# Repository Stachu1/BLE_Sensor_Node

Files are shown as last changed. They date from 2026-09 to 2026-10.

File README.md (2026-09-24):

# BLE Sensor Node

**BEng in Electronics Engineering thesis project, focused on low-power design and RF performance.**

A compact, coin-cell-powered Bluetooth Low Energy sensor node that measures temperature and
humidity and advertises the data periodically, without needing a persistent connection.

## Goal

Keep average current low enough for multi-year operation on a single CR2032 cell, while staying
within a small form factor. Main areas of work: low-power firmware and advertising strategy,
antenna/RF performance (chip vs. trace antenna), and power budgeting around the coin cell's
current limits.

Two BLE MCUs are being evaluated in parallel: **Nordic nRF54L** and **TI CC2340R5**.

## Repository Structure

```
hardware/
  N54/          BSN-N54 - Nordic nRF54L variant (KiCad project BSN-N54.kicad_pro)
  C23/          BSN-C23 - TI CC2340R5 variant
firmware/
  N54/          Firmware for BSN-N54 boards
  C23/          Firmware for BSN-C23 boards
docs/           Notes, datasheets, write-ups
results/        Power profiling logs, range-test data
```

The two MCU candidates are different chips (different pinout, power tree, likely BOM) rather
than build options of one board, so each gets its own KiCad project under `hardware/<variant>/`
and its own `firmware/<variant>/`, where `<variant>` is the variant code below. Both live side by side on `main` and iterate through normal
commits. Once a chip is selected, the other candidate's folder can be
archived or removed.

## Naming Scheme

Each board is identified as **`BSN-<variant>-<revision>`**, e.g. `BSN-N54-A`.

```
BSN-N54-A
 │   │  └─ PCB revision  (A, B, C …)
 │   └──── MCU variant   (N54 = Nordic nRF54L, C23 = TI CC2340R5)
 └──────── Board name    (BSN = BLE Sensor Node)
```

| Part | Values | Meaning |
|---|---|---|
| Board | `BSN` | BLE Sensor Node. Never changes. |
| Variant | `N54`, `C23` | First letter of the MCU part prefix (**n**RF54 → N, **C**C2340 → C) + MCU family number. Stays the same across parts in one family (e.g. nRF54L05/L10/L15). |
| Revision | `A`, `B`, `C` | Bare-PCB revision. Bumped only when copper or fab outputs change, i.e. when new boards are ordered. |
| Assembly option *(optional)* | e.g. `-UFL` | Population option on the same bare PCB (e.g. U.FL fitted instead of the chip antenna). Does not change the revision. |

Rules:

- **Each variant has its own revision counter.** `BSN-N54-C` and `BSN-C23-A` can exist at the same time.
- **Letters are only for boards that were ordered.** Work in progress before an order is still the upcoming letter.
  Once gerbers are sent to the fab that letter is frozen, and any later change means the next letter.
- **Reworked boards are not new revisions.** A hand-modified board is marked `A*` and the rework is noted in the variant README.
- **The ID is on the board itself.** The revision is set in the KiCad title block, and the ID is printed on the silkscreen.

Where the name appears:

| Item | Example |
|---|---|
| Hardware / firmware folder | `hardware/N54/`, `firmware/N54/` |
| KiCad project | `hardware/N54/BSN-N54.kicad_pro` |
| BOM in the repo | `hardware/N54/BSN-N54_BOM.csv` |
| Exported fab package | `BSN-N54-A_gerbers.zip`, `BSN-N54-A_BOM.csv`, `BSN-N54-A_pos.csv` |
| Git tag on the ordered commit | `hw/BSN-N54-A` |
| Firmware | board target `BSN_N54`, hardware revision `A` (also reported in the BLE Device Information Service) |

Boards:

| Board | MCU | Status |
|---|---|---|
| `BSN-N54-A` | nRF54L05 | Rev A layout done |
| `BSN-C23-A` | CC2340R5 | Copied from `BSN-N54-A`, MCU swap in progress |

## Status

Early stage — component evaluation and initial hardware/firmware design.

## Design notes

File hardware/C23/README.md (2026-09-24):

# BSN-C23 (TI CC2340R5 variant)

KiCad project: `BSN-C23.kicad_pro`. See the root README for the board naming scheme.

## Starting point

This project started as a copy of `BSN-N54-A` (board outline, power, sensors, antenna and
test points). Some parts are still nRF54L-specific and need to be replaced:

- [ ] U1: swap the nRF54L05 for the CC2340R52E0RGER (VQFN-24 4x4, RGE)
- [ ] Decoupling and power tree for the CC2340R5 (DC/DC inductor, VDDS/VDDR caps)
- [ ] 48 MHz HF crystal (the CC2340R5 uses 48 MHz; Y1 is currently the nRF 32 MHz part)
- [ ] RF matching network and filter per the TI CC2340R5 reference design
- [ ] Debug header: SWD pins for the CC2340R5

## CC2340R5 design resources

There is no CC2340 part in the official KiCad library and no TI equivalent of Nordic's
KiCad design blocks, so the design blocks table is empty for now.

| Resource | Format | Link |
|---|---|---|
| CC2340R5 symbol + footprint + STEP (RGE VQFN-24 4x4) | KiCad v6+ export via Ultra Librarian (free login) | https://vendor.ultralibrarian.com/TI/embedded/?gpn=CC2340R5&package=RGE&pin=24 |
| LP-EM-CC2340R53 LaunchPad design files (uses the 40-pin RKP package, but the RF, crystal and DC/DC circuits carry over) | Allegro/OrCAD + schematic/layout PDF, BOM, Gerbers, ODB++ | https://www.ti.com/lit/zip/SWRC397 |
| LP-EM-CC2340R53 user guide | PDF | https://www.ti.com/lit/pdf/SWRU637 |
| CC234x/CC27xx hardware configuration & PCB design (SWRA834) | PDF | https://www.ti.com/lit/pdf/SWRA834 |
| Product page (packages, docs) | Web | https://www.ti.com/product/CC2340R5 |

### CC2340R5 part in the `BSN-C23` library

| Part | Symbol | Footprint | 3D model |
|---|---|---|---|
| CC2340R52E0RGER (VQFN-24 4x4) | `CC2340R52E0RGER` | `Texas_RGE0024B_VQFN-24-1EP_4x4mm_P0.5mm_EP2.45x2.45mm_ThermalVias` | `Texas_RGE0024H_VQFN-24-1EP_4x4mm_P0.5mm_EP2.7x2.7mm.step` |

These were made here from the datasheet and KiCad's stock library rather than downloaded:

- **Symbol:** drawn from the datasheet (SWRS272F), Figure 6-2 and Tables 6-1 to 6-13. The exposed pad is pin 25 (GND).
- **Footprint:** KiCad's stock `VQFN-24-1EP_4x4mm_P0.5mm_EP2.45x2.45mm_ThermalVias`, renamed. It matches TI's RGE0024B land pattern (2.45 mm pad, 9 vias on a 0.975 mm grid). The signal pads are 0.775 mm long versus 0.6 mm in TI's example.
- **3D model:** KiCad has no STEP file for the 2.45 mm pad version. This one is the TI RGE0024H body, which is identical apart from a 2.7 mm exposed pad hidden under the package.

Next step: copy the RF matching network, crystals and DC/DC layout from the SWRC397 LaunchPad files.

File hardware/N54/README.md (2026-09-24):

# BSN-N54 (Nordic nRF54L variant)

KiCad project: `BSN-N54.kicad_pro`. See the root README for the board naming scheme.

## ANT-pin matching network

The antenna matching network on the nRF54L05 ANT pin (U1 pin 31) is a
3-section ladder plus two more tuning elements (L5, L6) leading to the
antenna-select junction (AE1 chip antenna / J1 SMA test point):

```
U1.ANT(31) -- L2(2.7n) --o-- L3(3.5n) --o-- L4(3.5n) --o-- L5(7.3n) -- L6(6.7n) -- (AE1 / J1)
                          |              |              |
                         C14(1.5p)      C15(2.0p)      C16(0.3p)
                          |              |              |
                         GND            GND            GND
```

From the nRF54L and antenna datasheets I estimated both the MCU ANT-pin
source impedance and the actual antenna impedance. Worked through on a
Smith chart, stepping from the estimated MCU source impedance through all
8 elements to the antenna:

https://onlinesmithchart.com/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

## Simplified 3-element equivalent

Considering a simplified network that achieves the same impedance
translation straight from the MCU source to the antenna, without forcing
the trace through 50 Ω partway — down to just 3 components:

https://onlinesmithchart.com/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

**Caveats:** the 8-element network likely also does 2nd/3rd-harmonic
low-pass filtering for regulatory compliance (FCC/ETSI spurious emissions),
which a bare 3-element network gives up some of; and both circuits above
use idealized lumped components — real inductors/capacitors have
parasitics, and the true MCU/antenna impedances include board parasitics
not captured here. Treat this as a starting point for simulation and bench
(VNA) verification, not a final BOM change.

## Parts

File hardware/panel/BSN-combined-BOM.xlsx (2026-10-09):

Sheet: Combined BOM
BLE Sensor Node - combined BOM (BSN-C23 + BSN-N54)
Generated from hardware/C23/BSN-C23.csv and hardware/N54/BSN-N54.csv. DNP-only parts (no part number) are not included.
Boards to build
BSN-C23 boards |  | 5 | Default 2 = one panel (2x C23 + 2x N54, see panel/panelize.py). Change to match the order.
BSN-N54 boards |  | 5
How to use
Yellow cells are for you to fill in: board counts above, Order qty and Unit price in the tables. Required qty = qty per board x boards to build. Total price = Order qty x Unit price.
Table 1 - DigiKey parts
# | DigiKey PN | Manufacturer | MPN | Value | Package | Description | C23 refs | C23 qty/board | N54 refs | N54 qty/board | Required qty | Order qty | Unit price | Total price | Notes
1 | 490-11248-1-ND | Murata | GJM1555C1HR30WB01D | 0.3p | 0402 | Cap 0.3pF 50V C0G |  | 0 | C16 | 1 | 5 | 10 | 0.52 | 5.24
2 | 490-8087-1-ND | Murata | GJM1555C1H1R5BB01D | 1.5p | 0402 | Cap 1.5pF 50V C0G | C7,C8 | 2 | C14 | 1 | 15 | 20 | 0.36 | 7.20
3 | 1276-CL21A107MQYNNWECT-ND | Murata | GRM21BR60J107ME15K | 100u | 0805 | Cap 100uF 6.3V X5R | C5 | 1 | C10 | 1 | 10 | 10 | 5.27 | 52.66
4 | 490-4516-1-ND | Murata | GRM155R71H103KA88D | 10n | 0402 | Cap 10nF 50V X7R |  | 0 | C8,C9 | 2 | 10 | 10 | 0.14 | 1.44
5 | 490-11191-1-ND | Murata | GJM1555C1H150FB01D | 15p | 0402 | Cap 15pF 50V C0G | C6 | 1 |  | 0 | 5 | 10 | 0.50 | 4.98
6 | 490-11205-1-ND | Murata | GJM1555C1H2R0WB01D | 2.0p | 0402 | Cap 2.0pF 50V C0G |  | 0 | C15 | 1 | 5 | 10 | 0.52 | 5.24
7 | 445-9028-1-ND | TDK | C1005X5R1V225K050BC | 2.2u | 0402 | Cap 2.2uF 35V X5R |  | 0 | C6,C7 | 2 | 10 | 10 | 0.76 | 7.60
8 | 490-15398-1-ND | Murata | LQW15AN2N7G8ZD | 2.7n | 0402 | Inductor 2.7nH RF |  | 0 | L2 | 1 | 5 | 10 | 0.90 | 9.04
9 | 490-LQW15AN2N8G80DCT-ND | Murata | LQW15AN2N8G80D | 2.8n | 0402 | Inductor 2.8nH RF | L1 | 1 |  | 0 | 5 | 10 | 0.88 | 8.78
10 | 490-15430-1-ND | Murata | LQW15AN3N5G8ZD | 3.5n | 0402 | Inductor 3.5nH RF |  | 0 | L3,L4 | 2 | 10 | 25 | 0.84 | 20.96
11 | 728-1074-1-ND | Seiko Instruments | SC32S-7PF20PPM | 32.768kHz | 3.2x1.5mm 2-pad | Crystal 32.768kHz |  | 1 | X2 | 1 | 10 | 10 | 2.47 | 24.69
12 | 478-CX3225FB32000C0FZZH1CT-ND | Kyocera AVX | CX3225FB32000C0FZZH1 | 32MHz | 3.2x2.5mm 4-pad | Crystal 32MHz |  | 0 | X1 | 1 | 5 | 10 | 1.95 | 19.45
13 | 490-12065-1-ND | Murata | LQM18PN4R7MFRL | 4.7u | 0603 | Inductor 4.7uH |  | 0 | L1 | 1 | 5 | 10 | 1.36 | 13.62
14 | 50-ECS-480-8-33B-CWN-TR3CT-ND | ECS Inc. | ECS-480-8-33B-CWN-TR3 | 48MHz | 3.2x2.5mm 4-pad | Crystal 48MHz | X1 | 1 |  | 0 | 5 | 10 | 2.77 | 27.71
15 | LQW15AN6N7G8ZD | Murata | LQW15AN6N7B00D | 6.7n | 0402 | Inductor 6.7nH RF | L2 | 1 | L6 | 1 | 10 | 25 | 0.84 | 20.96
16 | 490-6844-1-ND | Murata | LQW15AN7N3G00D | 7.3n | 0402 | Inductor 7.3nH RF | L3 | 1 | L5 | 1 | 10 | 25 | 0.63 | 15.72
17 | 535-AANI-CH-0138-Q-TCT-ND | Abracon | AANI-CH-0138-Q-T | AANI-CH-0138-Q-T | 7.0x2.0mm SMD | 2.4 GHz chip antenna | AE1 | 1 | AE1 | 1 | 10 | 10 | 5.14 | 51.42
18 | 296-CC2340R52E0RGERCT-ND | Texas Instruments | CC2340R52E0RGER | CC2340R52E0RGER | VQFN-24 4x4mm | BLE SoC | U1 | 1 |  | 0 | 5 | 10 | 17.94 | 179.40
19 | 123-A-BAT-CH-C8-EA-ZSR3CT-ND | Assmann WSW | A-BAT-CH-C8-EA-ZSR3 | CR2032_Holder | SMD | CR2032 coin cell holder | BT1 | 1 | BT1 | 1 | 10 | 10 | 3.54 | 35.37 | PCB footprint is Renata SMTU2032-LF, not this holder - check before ordering
20 | H11891CT-ND | Hirose | U.FL-R-SMT-1(10) | Conn_Coaxial_Small | SMD | U.FL receptacle, vertical | J1 | 1 | J1 | 1 | 10 | 10 | 9.28 | 92.81 | DNP on both boards (only for RF testing)
21 | 296-47774-1-ND | Texas Instruments | HDC2010YPAR | HDC2010 | DSBGA-6 | Humidity/temp sensor | U3 | 1 | U3 | 1 | 10 | 25 | 9.54 | 238.55
22 | 1649-SHTC3-TR-2.5KSCT-ND | Sensirion | SHTC3-TR-2.5KS | SHTC3 | DFN-4 2x2mm | Humidity/temp sensor | U2 | 1 | U2 | 1 | 10 | 5 | 12.48 | 62.42 | DNP on both boards (alternative to HDC2010)
23 | 4823-NRF54L05-QFAA-RCT-ND | Nordic Semiconductor | NRF54L05-QFAA-R | nRF54L05-QFXX | QFN-48 6x6mm | BLE SoC |  | 0 | U1 | 1 | 5 | 10 | 21.51 | 215.10
24 | 1568-18569-ND | SparkFun Electronics | 18569 |  |  |  |  |  |  |  | 1 | 2 | 19.26 | 38.52
25 | 315-NC191LT10-ND | Chip Quik Inc. | NC191LT10 |  |  |  |  |  |  |  | 1 | 1 | 52.07 | 52.07
 |  |  |  |  |  |  |  |  |  |  |  |  | Subtotal | 1210.95
Table 2 - AX parts
# | AX no. |  |  | Value | Package | Description | C23 refs | C23 qty/board | N54 refs | N54 qty/board | Required qty | Order qty | Unit price | Total price | Notes
1 | 73236 |  |  | 100R@100MHz | 0603 | Ferrite bead |  | 0 | FB1 | 1 | 5
2 | 201003 |  |  | 100k | 0402 | Resistor | R3 | 1 |  | 0 | 5
3 | 27726 |  |  | 100n | 0402 | Capacitor | C2,C3,C4,C11,C12,C17,C18 | 7 | C2,C3,C4,C5,C12,C13 | 6 | 65
4 | 27204 |  |  | 10u | 0603 | Capacitor | C1,C10 | 2 | C1 | 1 | 15
5 | 73170 |  |  | 10u | 0603 | Inductor | L5 | 1 |  | 0 | 5
6 | 201001 |  |  | 1k | 0402 | Resistor |  | 0 | R1 | 1 | 5
7 | 27730 |  |  | 1u | 0402 | Capacitor | C13 | 1 |  | 0 | 5
8 | 204701 |  |  | 4.7k | 0402 | Resistor | R1,R2 | 2 | R2,R3 | 2 | 20
 |  |  |  |  |  |  |  |  |  |  |  |  | Subtotal | 0.00
 |  |  |  |  |  |  |  |  |  |  |  |  | Grand total | 1210.95

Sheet: Sheet1
DigiKey PN | Manufacturer | MPN | Order qty
490-11248-1-ND | Murata | GJM1555C1HR30WB01D | 10
490-8087-1-ND | Murata | GJM1555C1H1R5BB01D | 20
1276-CL21A107MQYNNWECT-ND | Samsung | CL21A107MQYNNWE | 10
490-4516-1-ND | Murata | GRM155R71H103KA88D | 10
490-11191-1-ND | Murata | GJM1555C1H150FB01D | 10
490-11205-1-ND | Murata | GJM1555C1H2R0WB01D | 10
445-9028-1-ND | TDK | C1005X5R1V225K050BC | 10
490-15398-1-ND | Murata | LQW15AN2N7G8ZD | 10
490-LQW15AN2N8G80DCT-ND | Murata | LQW15AN2N8G80D | 10
490-15430-1-ND | Murata | LQW15AN3N5G8ZD | 25
728-1074-1-ND | Seiko Instruments | SC32S-7PF20PPM | 10
478-CX3225FB32000C0FZZH1CT-ND | Kyocera AVX | CX3225FB32000C0FZZH1 | 10
490-12065-1-ND | Murata | LQM18PN4R7MFRL | 10
50-ECS-480-8-33B-CWN-TR3CT-ND | ECS Inc. | ECS-480-8-33B-CWN-TR3 | 10
LQW15AN6N7G8ZD | Murata | LQW15AN6N7B00D | 25
490-6844-1-ND | Murata | LQW15AN7N3G00D | 25
535-AANI-CH-0138-Q-TCT-ND | Abracon | AANI-CH-0138-Q-T | 10
296-CC2340R52E0RGERCT-ND | Texas Instruments | CC2340R52E0RGER | 10
123-A-BAT-CH-C8-EA-ZSR3CT-ND | Assmann WSW | A-BAT-CH-C8-EA-ZSR3 | 10
H11891CT-ND | Hirose | U.FL-R-SMT-1(10) | 10
296-47774-1-ND | Texas Instruments | HDC2010YPAR | 25
1649-SHTC3-TR-2.5KSCT-ND | Sensirion | SHTC3-TR-2.5KS | 5
4823-NRF54L05-QFAA-RCT-ND | Nordic Semiconductor | NRF54L05-QFAA-R | 10
1568-18569-ND | SparkFun Electronics | 18569 | 2
315-NC191LT10-ND | Chip Quik Inc. | NC191LT10 | 1

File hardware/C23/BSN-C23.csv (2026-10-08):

Reference | Qty | Value | DigiKey | AX
AE1 | 1 | AANI-CH-0138-Q-T | 535-AANI-CH-0138-Q-TCT-ND
BT1 | 1 | CR2032_Holder | 123-A-BAT-CH-C8-EA-ZSR3CT-ND
C1,C10 | 2 | 10u |  | 27204
C2,C3,C4,C11,C12,C17,C18 | 7 | 100n |  | 27726
C5 | 1 | 100u | 490-GRM21BR60J107ME15KCT-ND
C6 | 1 | 15p | 490-11191-1-ND
C7,C8 | 2 | 1.5p | 490-8087-1-ND
C13 | 1 | 1u |  | 27730
J1 | 1 | Conn_Coaxial_Small | H11891CT-ND
L1 | 1 | 2.8n | 490-LQW15AN2N8G80DCT-ND
L2 | 1 | 6.7n | 490-LQW15AN6N7B00DCT-ND
L3 | 1 | 7.3n | 490-6844-1-ND
L5 | 1 | 10u |  | 73170
R1,R2 | 2 | 4.7k |  | 204701
R3 | 1 | 100k |  | 201003
U1 | 1 | CC2340R52E0RGER | 296-CC2340R52E0RGERCT-ND
U2 | 1 | SHTC3 | 1649-SHTC3-TR-2.5KSCT-ND
U3 | 1 | HDC2010 | 296-47774-1-ND
X1 | 1 | 48MHz | 50-ECS-480-8-33B-CWN-TR3CT-ND

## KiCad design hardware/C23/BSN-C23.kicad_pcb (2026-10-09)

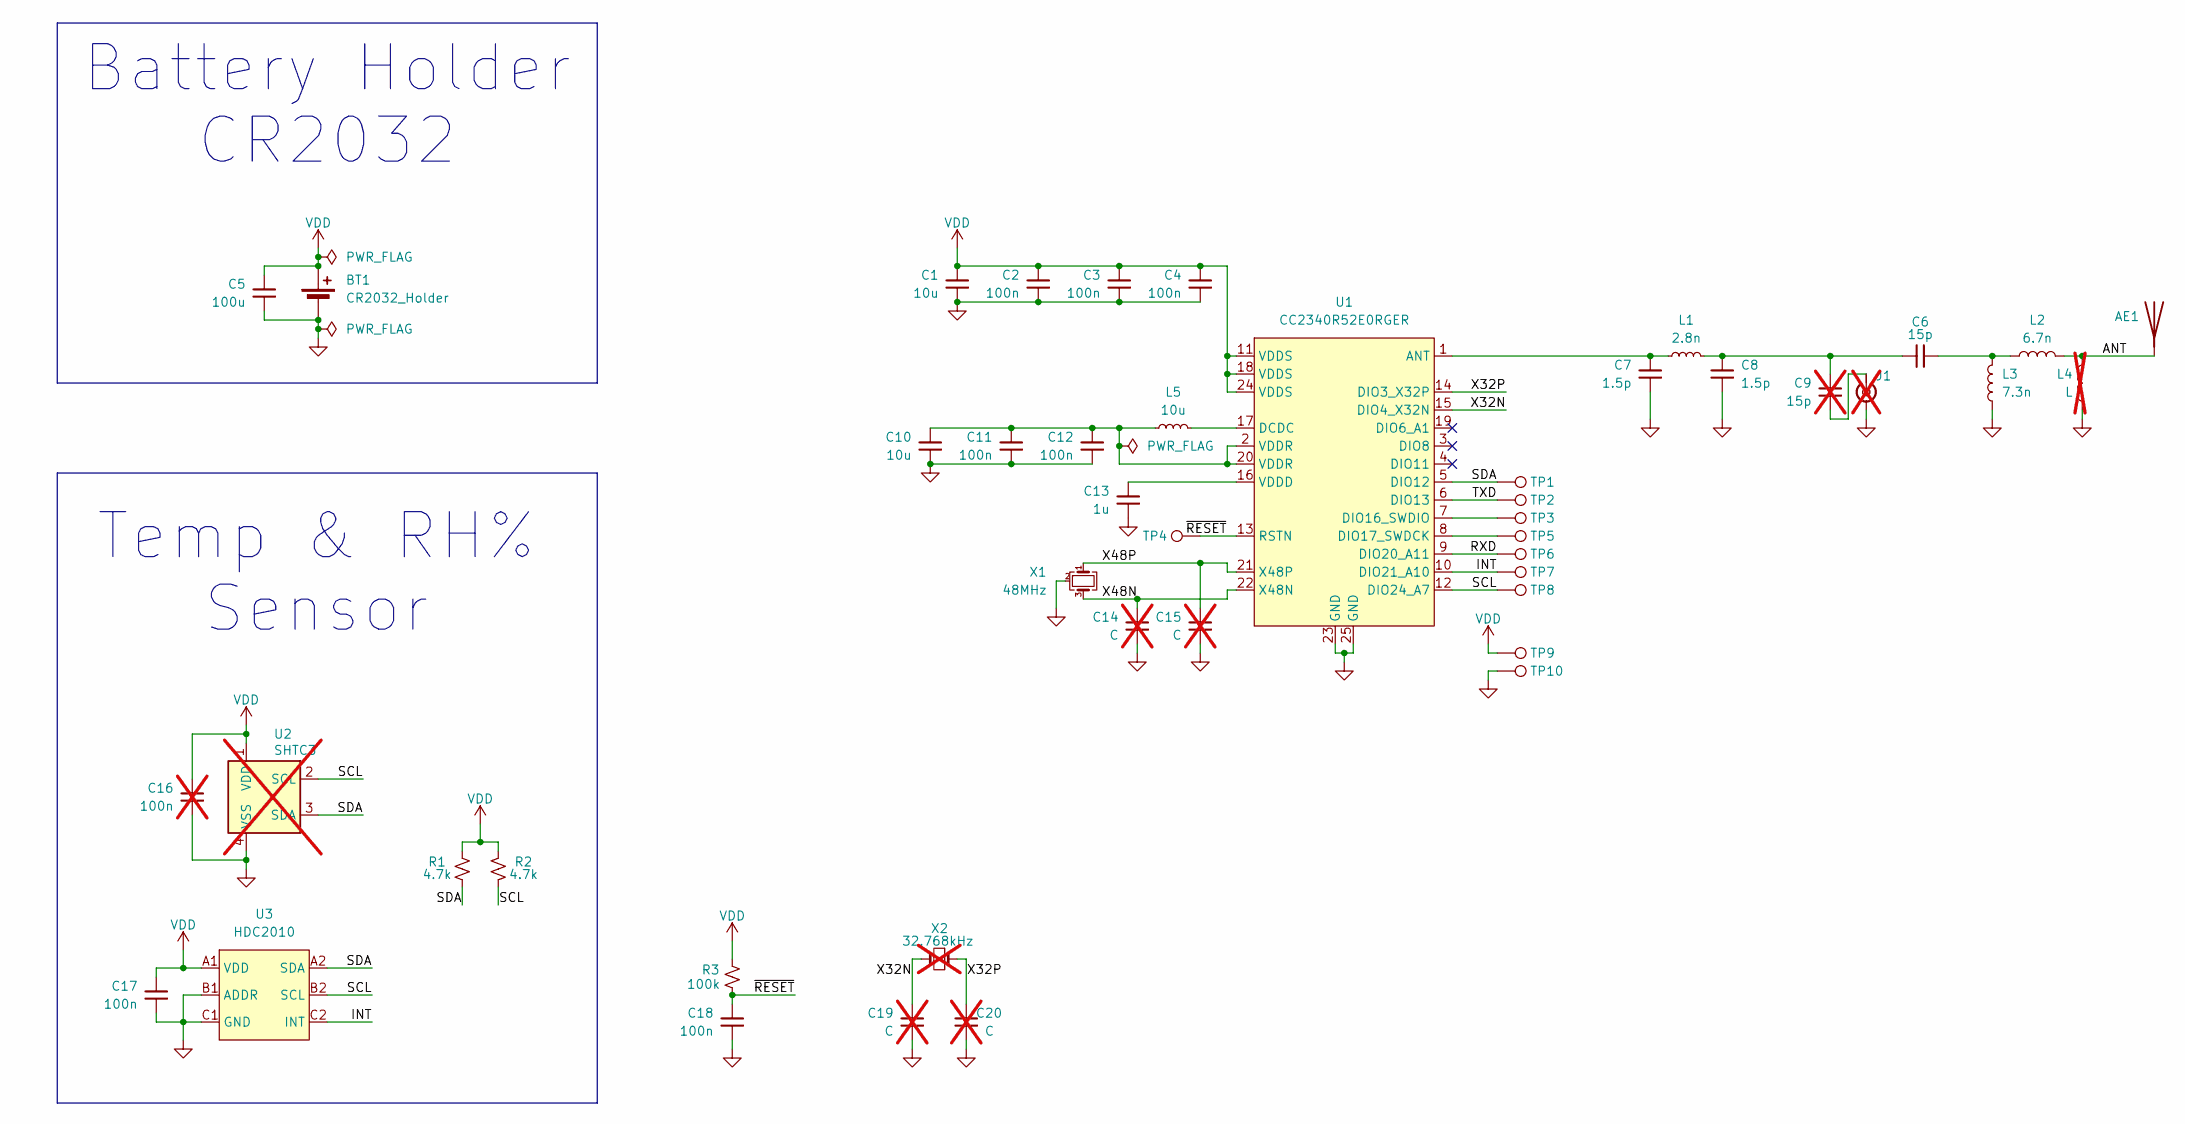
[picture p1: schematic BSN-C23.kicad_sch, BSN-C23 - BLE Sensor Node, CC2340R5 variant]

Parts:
AE1: AANI-CH-0138-Q-T; DigiKey 535-AANI-CH-0138-Q-TCT-ND
BT1: CR2032_Holder; BatteryHolder_Renata_SMTU2032-LF_1x2032; DigiKey 123-A-BAT-CH-C8-EA-ZSR3CT-ND
C1, C10: 10u; C_0603_1608Metric
C2, C3, C4, C11, C12, C17, C18: 100n; C_0402_1005Metric
C5: 100u; C_0805_2012Metric; DigiKey 490-GRM21BR60J107ME15KCT-ND
C6: 15p; C_0402_1005Metric; DigiKey 490-11191-1-ND
C7, C8: 1.5p; C_0402_1005Metric; DigiKey 490-8087-1-ND
C9: 15p; C_0402_1005Metric; DigiKey 490-11191-1-ND; not fitted
C13: 1u; C_0402_1005Metric
C14, C15, C19, C20: C; C_0402_1005Metric; not fitted
C16: 100n; C_0402_1005Metric; not fitted
J1: Conn_Coaxial_Small; U.FL_Hirose_U.FL-R-SMT-1_Vertical; DigiKey H11891CT-ND; not fitted
L1: 2.8n; L_0402_1005Metric; DigiKey 490-LQW15AN2N8G80DCT-ND
L2: 6.7n; L_0402_1005Metric; DigiKey 490-LQW15AN6N7B00DCT-ND
L3: 7.3n; L_0402_1005Metric; DigiKey 490-6844-1-ND
L4: L; L_0402_1005Metric; not fitted
L5: 10u; L_0603_1608Metric
R1, R2: 4.7k; R_0402_1005Metric
R3: 100k; R_0402_1005Metric
TP1, TP2, TP4, TP6, TP7, TP8: TestPoint; TestPoint_Pad_D1.0mm
TP3, TP5, TP9, TP10: TestPoint; TestPoint_Pad_D1.5mm
U1: CC2340R52E0RGER; Texas_RGE0024B_VQFN-24-1EP_4x4mm_P0.5mm_EP2.45x2.45mm_Therm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; DigiKey 296-CC2340R52E0RGERCT-ND
U2: SHTC3; Sensirion_DFN-4-1EP_2x2mm_P1mm_EP0.7x1.6mm; DigiKey 1649-SHTC3-TR-2.5KSCT-ND; not fitted
U3: HDC2010; DigiKey 296-47774-1-ND
X1: 48MHz; Crystal_SMD_3225-4Pin_3.2x2.5mm; DigiKey 50-ECS-480-8-33B-CWN-TR3CT-ND
X2: 32.768kHz; Crystal_SMD_3215-2Pin_3.2x1.5mm; DigiKey 728-1074-1-ND; not fitted

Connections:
/ANT: AE1.1 (Feed_1), L2.2, L4.1
/INT: TP7.1 (1_1), U1.10 (DIO21_A10), U3.C2 (INT)
/RXD: TP6.1 (1_1), U1.9 (DIO20_A11)
/SCL: R2.1, TP8.1 (1_1), U1.12 (DIO24_A7), U2.2 (SCL), U3.B2 (SCL)
/SDA: R1.1, TP1.1 (1_1), U1.5 (DIO12), U2.3 (SDA), U3.A2 (SDA)
/TXD: TP2.1 (1_1), U1.6 (DIO13)
/X32N: C19.1, U1.15 (DIO4_X32N), X2.2
/X32P: C20.1, U1.14 (DIO3_X32P), X2.1
/X48N: C14.1, U1.22 (X48N), X1.3
/X48P: C15.1, U1.21 (X48P), X1.1
/~RESET: C18.1, R3.1, TP4.1 (1_1), U1.13 (RSTN)
GND: BT1.2 (-), C1.2, C2.2, C3.2, C4.2, C5.2, C7.2, C8.2, C10.2, C11.2, C12.2, C13.2, C14.2, C15.2, C16.2, C17.2, C18.2, C19.2, C20.2, J1.2 (Ext), L3.1, L4.2, TP10.1 (1_1), U1.23 (GND), U1.25 (GND), U2.4 (VSS), U3.B1 (ADDR), U3.C1 (GND), X1.2 (G), X1.4 (G)
unnamed: C6.1, L2.1, L3.2
unnamed: C6.2, C8.1, C9.1, L1.2
unnamed: C10.1, C11.1, C12.1, L5.1, U1.2 (VDDR), U1.20 (VDDR)
unnamed: C9.2, J1.1 (In)
unnamed: C7.1, L1.1, U1.1 (ANT)
unnamed: L5.2, U1.17 (DCDC)
unnamed: TP3.1 (1_1), U1.7 (DIO16_SWDIO)
unnamed: TP5.1 (1_1), U1.8 (DIO17_SWDCK)
unnamed: C13.1, U1.16 (VDDD)
VDD: BT1.1 (+), C1.1, C2.1, C3.1, C4.1, C5.1, C16.1, C17.1, R1.2, R2.2, R3.2, TP9.1 (1_1), U1.11 (VDDS), U1.18 (VDDS), U1.24 (VDDS), U2.1 (VDD), U3.A1 (VDD)

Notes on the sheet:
Battery Holder CR2032
Temp & RH% Sensor

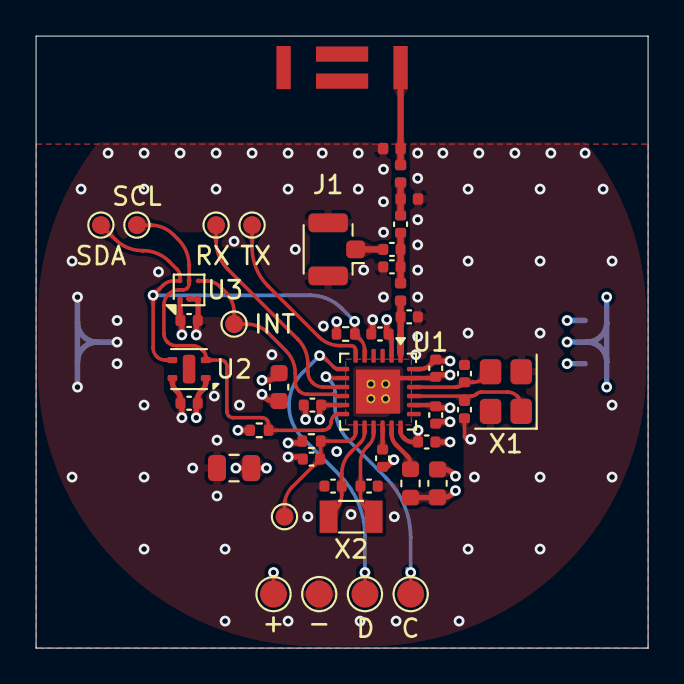
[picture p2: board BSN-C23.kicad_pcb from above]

Board: 4 copper layers, 34.0 x 34.0 mm, 46 parts (1 on the bottom side), 22 nets.

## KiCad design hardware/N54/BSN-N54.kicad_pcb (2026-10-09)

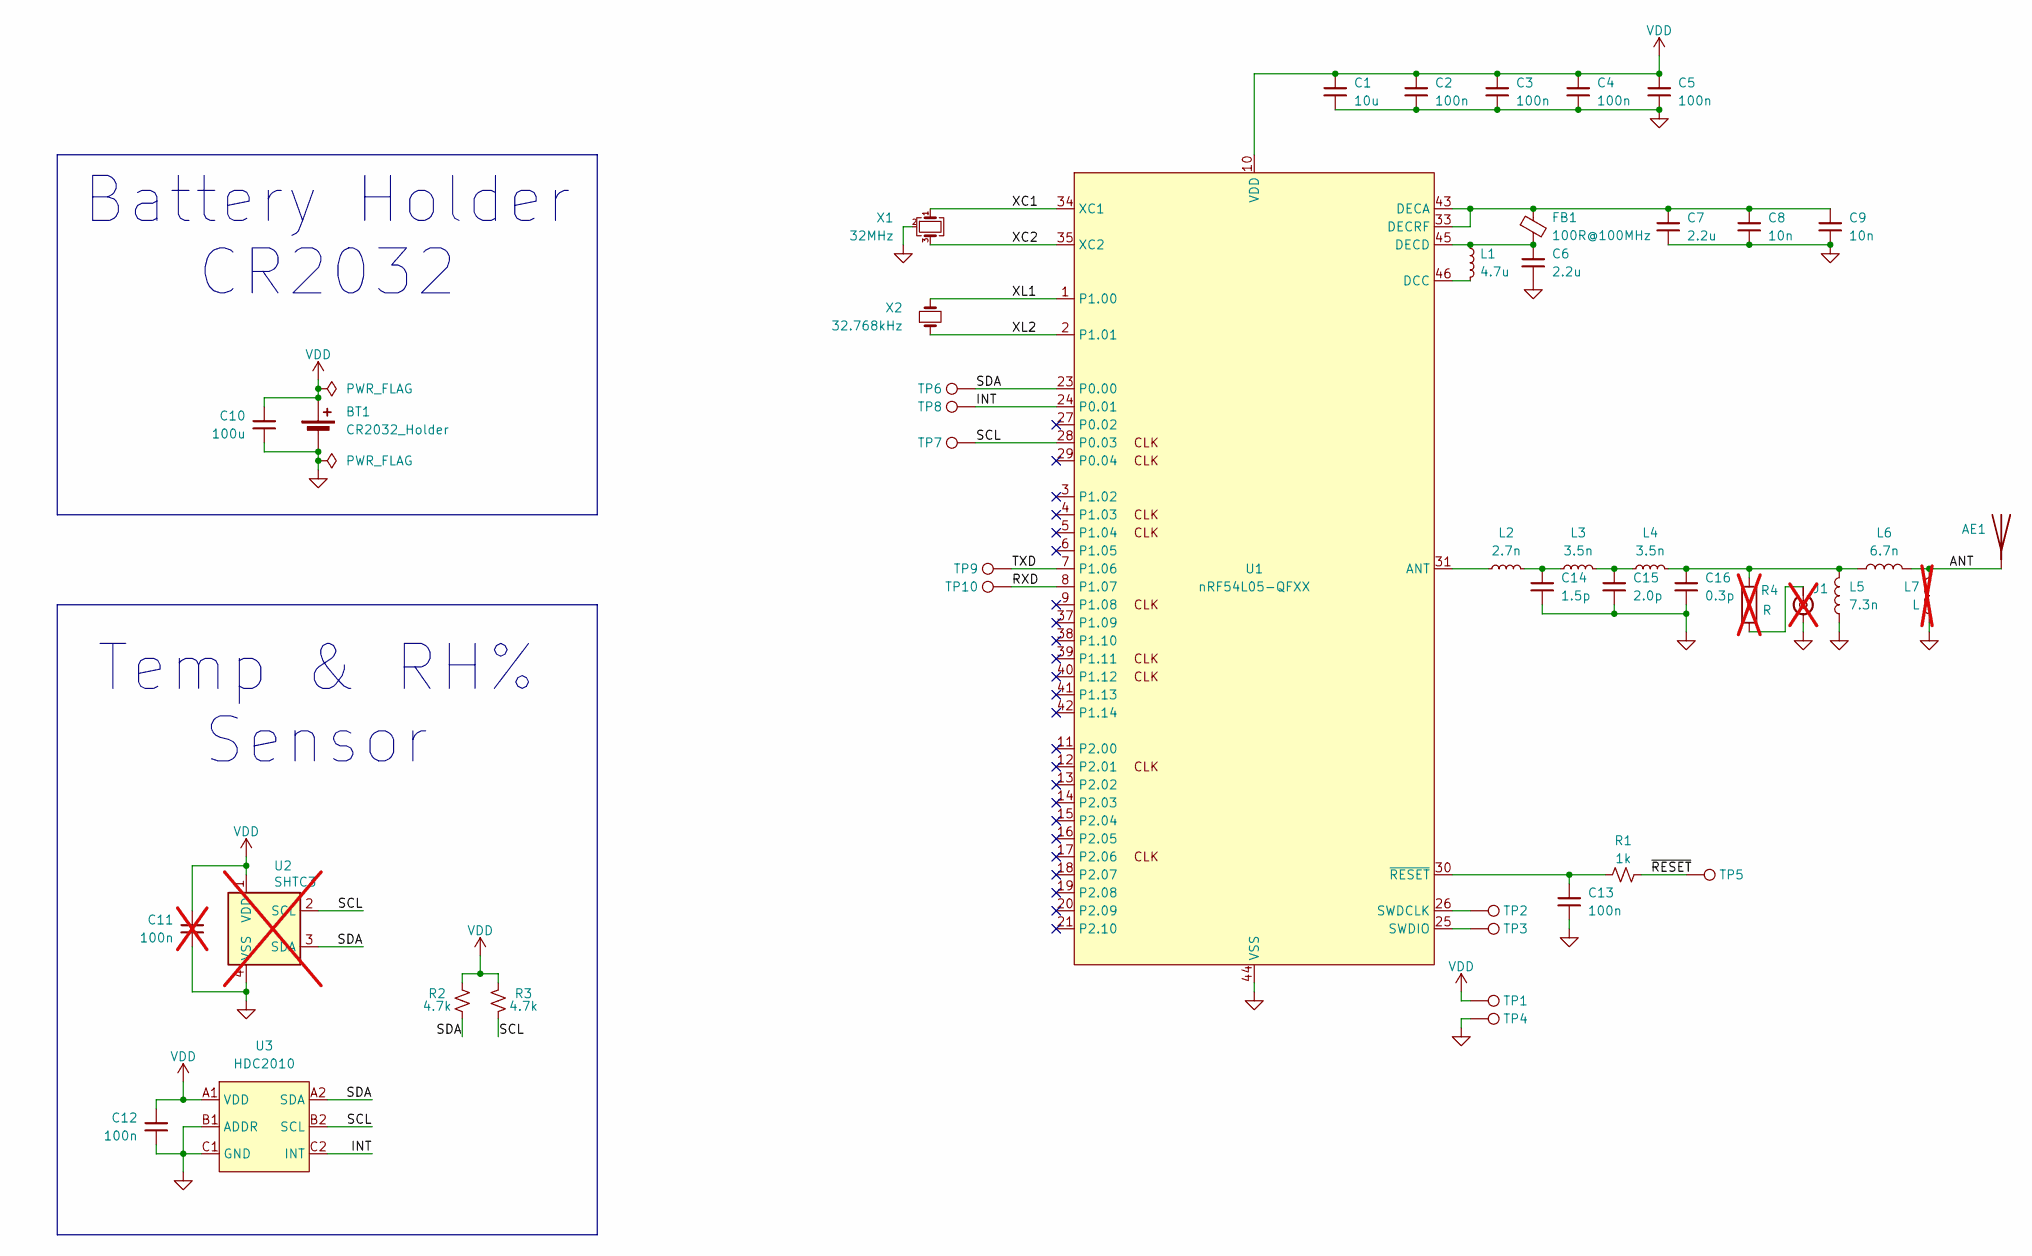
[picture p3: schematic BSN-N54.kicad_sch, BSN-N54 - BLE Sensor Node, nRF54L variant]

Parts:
AE1: AANI-CH-0138-Q-T; DigiKey 535-AANI-CH-0138-Q-TCT-ND
BT1: CR2032_Holder; BatteryHolder_Renata_SMTU2032-LF_1x2032; DigiKey 123-A-BAT-CH-C8-EA-ZSR3CT-ND
C1: 10u; C_0603_1608Metric
C2, C3, C4, C5, C12, C13: 100n; C_0402_1005Metric
C6, C7: 2.2u; C_0402_1005Metric; DigiKey 445-9028-1-ND
C8, C9: 10n; C_0402_1005Metric; DigiKey 490-4516-1-ND
C10: 100u; C_0805_2012Metric; DigiKey 490-GRM21BR60J107ME15KCT-ND
C11: 100n; C_0402_1005Metric; not fitted
C14: 1.5p; C_0402_1005Metric; DigiKey 490-8087-1-ND
C15: 2.0p; C_0402_1005Metric; DigiKey 490-11205-1-ND
C16: 0.3p; C_0402_1005Metric; DigiKey 490-11248-1-ND
FB1: 100R@100MHz; L_0603_1608Metric
J1: Conn_Coaxial_Small; U.FL_Hirose_U.FL-R-SMT-1_Vertical; DigiKey H11891CT-ND; not fitted
L1: 4.7u; L_0603_1608Metric; DigiKey 490-12065-1-ND
L2: 2.7n; L_0402_1005Metric; DigiKey 490-15398-1-ND
L3, L4: 3.5n; L_0402_1005Metric; DigiKey 490-15430-1-ND
L5: 7.3n; L_0402_1005Metric; DigiKey 490-6844-1-ND
L6: 6.7n; L_0402_1005Metric; DigiKey 490-LQW15AN6N7B00DCT-ND
L7: L; L_0402_1005Metric; not fitted
R1: 1k; R_0402_1005Metric
R2, R3: 4.7k; R_0402_1005Metric
R4: R; R_0201_0603Metric; not fitted
TP1, TP2, TP3, TP4: TestPoint; TestPoint_Pad_D1.5mm
TP5, TP6, TP7, TP8, TP9, TP10: TestPoint; TestPoint_Pad_D1.0mm
U1: nRF54L05-QFXX; VQFN-48-1EP_6x6mm_P0.4mm_EP4.1x4.1mm_ThermalVias; DigiKey 4823-NRF54L05-QFAA-RCT-ND
U2: SHTC3; Sensirion_DFN-4-1EP_2x2mm_P1mm_EP0.7x1.6mm; DigiKey 1649-SHTC3-TR-2.5KSCT-ND; not fitted
U3: HDC2010; DigiKey 296-47774-1-ND
X1: 32MHz; Crystal_SMD_3225-4Pin_3.2x2.5mm; DigiKey 478-CX3225FB32000C0FZZH1CT-ND
X2: 32.768kHz; Crystal_SMD_3215-2Pin_3.2x1.5mm; DigiKey 728-1074-1-ND

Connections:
/ANT: AE1.1 (Feed_1), L6.2, L7.1
/INT: TP8.1 (1_1), U1.24 (P0.01), U3.C2 (INT)
/RXD: TP10.1 (1_1), U1.8 (P1.07)
/SCL: R3.1, TP7.1 (1_1), U1.28 (P0.03), U2.2 (SCL), U3.B2 (SCL)
/SDA: R2.1, TP6.1 (1_1), U1.23 (P0.00), U2.3 (SDA), U3.A2 (SDA)
/TXD: TP9.1 (1_1), U1.7 (P1.06)
/XC1: U1.34 (XC1), X1.1
/XC2: U1.35 (XC2), X1.3
/XL1: U1.1 (P1.00), X2.2
/XL2: U1.2 (P1.01), X2.1
/~RESET: R1.2, TP5.1 (1_1)
GND: BT1.2 (-), C1.2, C2.2, C3.2, C4.2, C5.2, C6.2, C7.2, C8.2, C9.2, C10.2, C11.2, C12.2, C13.2, C14.2, C15.2, C16.2, J1.2 (Ext), L5.1, L7.2, TP4.1 (1_1), U1.32 (VSS_PA), U1.44 (VSS), U1.49 (VSS), U2.4 (VSS), U3.B1 (ADDR), U3.C1 (GND), X1.2 (G), X1.4 (G)
unnamed: C14.1, L2.2, L3.1
unnamed: C15.1, L3.2, L4.1
unnamed: C16.1, L4.2, L5.2, L6.1, R4.1
unnamed: J1.1 (In), R4.2
unnamed: L2.1, U1.31 (ANT)
unnamed: L1.2, U1.46 (DCC)
unnamed: C7.1, C8.1, C9.1, FB1.1, U1.33 (DECRF), U1.43 (DECA)
unnamed: C6.1, FB1.2, L1.1, U1.45 (DECD)
unnamed: TP2.1 (1_1), U1.26 (SWDCLK)
unnamed: TP3.1 (1_1), U1.25 (SWDIO)
unnamed: C13.1, R1.1, U1.30 (~RESET)
VDD: BT1.1 (+), C1.1, C2.1, C3.1, C4.1, C5.1, C10.1, C11.1, C12.1, R2.2, R3.2, TP1.1 (1_1), U1.10 (VDD), U1.22 (VDD), U1.36 (VDD), U1.47 (VDD), U1.48 (VDD), U2.1 (VDD), U3.A1 (VDD)

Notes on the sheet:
Battery Holder CR2032
Temp & RH% Sensor

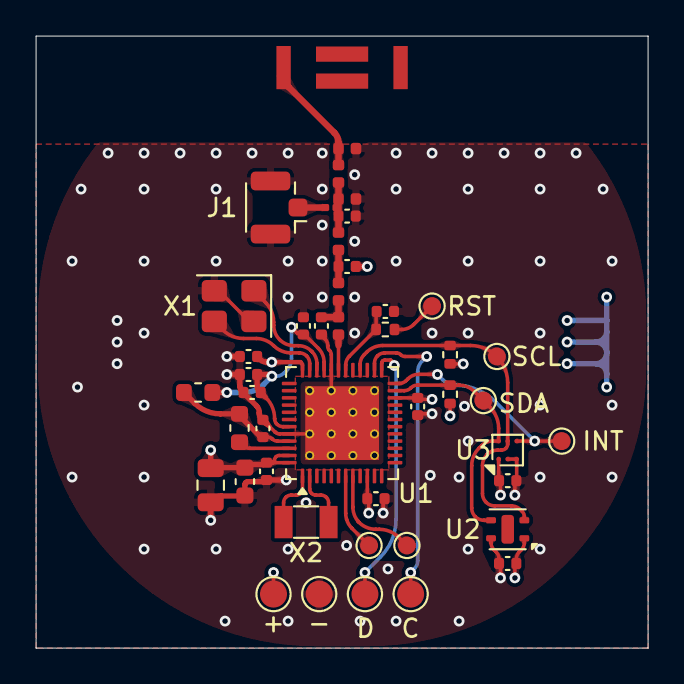
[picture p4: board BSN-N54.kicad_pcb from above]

Board: 4 copper layers, 34.0 x 34.0 mm, 46 parts (1 on the bottom side), 24 nets.

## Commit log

2026-09-14 Files structure & Began nRF54L schematics design
    [BLE_Sensor_Node.kicad_pcb, BLE_Sensor_Node.kicad_sch]
2026-09-17 nRF schematics rev: A
    [BLE_Sensor_Node.kicad_sch]
2026-09-17 nRF54 variant routing
    [BLE_Sensor_Node.kicad_pcb, BLE_Sensor_Node.kicad_sch]
2026-09-21 Added optional U.FL connector and stiching vias
    [BLE_Sensor_Node.kicad_pcb, BLE_Sensor_Node.kicad_sch]
2026-09-24 First Rev of the nRF variant
    [BLE_Sensor_Node.kicad_pcb, BLE_Sensor_Node.kicad_sch, BOM.csv]
2026-09-24 Adopted BSN-<variant>-<rev> naming scheme
    Renamed variant folders to N54/C23 and the nRF KiCad project to BSN-N54, documented the naming scheme in README.
    [BSN-N54.kicad_pcb, BSN-N54.kicad_sch, BSN-N54_BOM.csv]
2026-09-24 Added BSN-C23 project based on BSN-N54
    Copied the nRF project as the starting point for the TI variant, added CC2340R5 RKP (Ultra Librarian) and RGE parts to its library, documented TI design resources.
    [BSN-C23.kicad_pcb, BSN-C23.kicad_sch, BSN-C23_BOM.csv]
2026-09-24 Cleaned up libraries for both variants
    Renamed the project libraries to BSN-N54 / BSN-C23 and updated lib tables and all references, removed Nordic parts and the unused 40-pin CC2340 package from the C23 library, synced Antenna symbol fie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
    [BSN-C23.kicad_pcb, BSN-C23.kicad_sch, BSN-N54.kicad_pcb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]
2026-09-24 Slikscreen cleanup
    [BSN-N54.kicad_pcb]
2026-09-24 C23 variant schematics and component allocation fixes - work in progress
    [BSN-C23.kicad_sch, BSN-N54.kicad_pcb, BSN-N54.kicad_sch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]
2026-09-25 Matched components & Footrpints. Small routing changes on N54
    [BSN-C23.kicad_sch, BSN-C23_BOM.csv, BSN-N54.kicad_pcb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]
2026-09-25 Started C23 varant layout
    [BSN-C23.kicad_pcb, BSN-C23.kicad_sch]
2026-09-28 Progress on C23 layout & Routing
    [BSN-C23.kicad_pcb, BSN-N54.kicad_pcb]
2026-09-30 Moved the U.FL connector closer to the matching network
    [BSN-N54.kicad_pcb]
2026-09-30 Rounded tracks
    [BSN-N54.kicad_pcb]
2026-09-30 Added some vias
    [BSN-N54.kicad_pcb]
2026-09-30 More vias & SDA lables on silkscreen
    [BSN-C23.kicad_pcb]
2026-09-30 Added teardrops
    [BSN-C23.kicad_pcb]
2026-09-30 Added UART test points
    [BSN-N54.kicad_pcb, BSN-N54.kicad_sch]
2026-09-30 Added KiKit panel of C23 and N54
    [BSN-panel.kicad_pcb]
2026-10-08 Small routing / copper pours fixes
    [BSN-C23.kicad_pcb]
2026-10-08 Readded teardrops on VDD net
    [BSN-C23.kicad_pcb]
2026-10-08 Small routing fixes
    [BSN-N54.kicad_pcb]
2026-10-08 More small fixes & Created new panel
    [BSN-C23.csv, BSN-C23.kicad_pcb, BSN-N54.csv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]
2026-10-08 Created order sheet
    [BSN-combined-BOM.xlsx]
2026-10-09 Exported and ordered
    [BSN-C23.kicad_pcb, BSN-N54.kicad_pcb, BSN-combined-BOM.xlsx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]
2026-10-22 Add BSN-C23 firmware, bring-up plan and BLE scanner
    - hwtest: no-BLE self-test (HFXT, LFOSC, VDDS, I2C, HDC2010 + INT line),
    PASS/FAIL report over UART on TP2
    - ble_sensor: BTHome v2 broadcaster (temp, RH, VDD, battery), 1 s
    advertising, 10 s sensor period, LFOSC sleep clock (X2 DNP)
    - common: board pin map, UART logger, HDC2010 and SHTC3 drivers
    - test: host unit tests against a fake I2C bus
    - tools/bsn_scan.py: PC BLE scanner that filters by MAC and decodes BTHome
    - Build with TI Arm Clang 4.0.4.LTS + SysConfig 1.26.4 + LPF3 SDK 9.23;
    flash via XDS110 (make flash) or J-Link (make jflash)
    - BRINGUP.md: staged bring-up and early test plan
    Board #1 (FC:DE:C5:73:2F:4E): hwtest 13/13 PAS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
2026-10-23 Add BSN-C23 antenna matching measurements
    VNA sweeps (Keysight P9370B, 1-3.5 GHz) and write-up of matching AE1
    (AANI-CH-0138) on an RF-only Rev A test board.
    - L2 3.3 nH series + 2.0 pF on the L3 pads: S11 <= -11 dB over
    2.40-2.48 GHz, -18.8 dB at 2.44 GHz (without battery)
    - TI reference L2 (6.7 nH) is ~3x too much inductance for this layout
    - First readings were rotated by ~22 cm of uncorrected cable; redone
    with the reference plane at the board (open/short checks included)
    - Battery fitted detunes the antenna to 9.5+j12.3 ohm (-3.1 dB);
    re-match with battery is an open item
2026-10-23 Document BSN-C23-A bring-up and antenna matching status
    - hardware/C23/README: rev A population, RF network, bring-up status,
    antenna matching summary (L2 3.3 nH, 2.0 pF shunt, no battery) and rework log
    - BRINGUP: board #1 results (diode check, ~4 mA blank, SWD, hwtest 13/13),
    matching status in stages 4 and 6
    - README: C23-A board status
2026-10-23 Add BSN-C23 continuous-wave RF test firmware
    - cwtest: unmodulated carrier for harmonic/spurious measurements, no BLE
    stack (RCL TX_TEST with sendCw, no stop time)
    - Frequency and power set at build time: make FREQ_MHZ=2440 TX_DBM=0
    (2360..2500 MHz, PA table -20..+8 dBm); changing them triggers a rebuild
    - Prints carrier, actual PA setting and VDDS once on the UART, then idles it
    - README: RF carrier test section
2026-10-26 Re-match BSN-C23 antenna with the battery connector fitted
    - Sweeps s11_08..s11_12 (2026-10-26) on the RF test board with the
    battery connector fitted; the raised board detunes the antenna, the
    cell itself makes almost no difference
    - Final match: L2 4.3 nH series, 2.1 pF on the L3 pads, -32.1 dB at
    2.44 GHz, better than -10.3 dB across 2.40-2.48 GHz
    - ANTENNA_MATCHING: new results, notes on tuning L2 first (real part of
    admittance to 20 mS) and the cap second, model drift, bandwidth limit
    - C23 README, BRINGUP and root README updated with the tuned values
2026-10-26 Trim BSN-C23 HFXT cap array and record carrier measurements
    - HFXT cap trim overridden to Q1 = Q2 = 44 in ble_sensor and cwtest:
    the factory value 35 put the 2440 MHz carrier at +30.3 ppm, 39 gave
    +16.8 ppm and 44 gives +2.2 ppm (about 3 ppm per step)
    - cwtest prints the HFXT cap trim in use at startup
    - testing/RF_CARRIER.md and cw_01..06 sweeps: VNA used as a receiver
    (A,2), 0.67 dB thru offset, 2414 MHz image response, output power at
    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
2026-10-26 Record BSN-C23 advertising and floor current measurements
    Measured on board #1 (antenna matched, U2 fitted) with a Keysight 34461A:
    sleep floor 0.366 uA with or without the BLE stack, 12.6 uC per advertising
    event at 0 dBm (+34 % at 2.0 V, -8 % at -8 dBm, +116 % at +8 dBm), and
    16.1 uA for the full firmware at 1 s advertising, which matches the model
    plus the sensor task's 1 s wake-ups. The earlier 0.925 uA floor came from
    a reset that left the debug logic powered; shutdown stays unresolved.
    ble_sensor gains build options for measurements (LOG, ADV_MS, TX_DBM,
    SENSOR_S, ADV). pwrtest sets the DIO21 rising edge at runtime, because the
    SysConfig trigger kept the board at 2.3 mA in the static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
2026-10-27 Add BSN-C23 RAM log readable over the J-Link
    hwtest can keep its log in a RAM ring buffer (BSN_LOG_RAM=1), read back with
    tools/jlink_log.py, for boards without a UART adapter.
2026-10-27 Add BSN-N54 firmware: hwtest, ble_sensor, cwtest and pwrtest
    nRF Connect SDK v3.4.0 apps mirroring firmware/C23 app for app and option for
    option, with a devicetree overlay that turns the nrf54l15dk/nrf54l05 target
    into the BSN-N54-A board. Includes the bring-up procedure and the settings
    found on boards #1 and #2:
    - LF clock from the internal RC (X2 not fitted), calibrated as rarely as MPSL
    allows (the default cost about 0.7 uA of floor current)
    - HFXO load capacitance 11.75 pF (7 pF from the datasheet gave +127 ppm)
    - cwtest PATTERN option to send single FSK tones for checking the offset
    - RTT, HFXO_CL_FF and DCDC build options, and a clean-build fallback for the
    NCS reconfigure error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
2026-10-27 Record BSN-N54 RF and current measurements and the C23 no-pi board
    - N54 board #2: HFXO trimmed to 11.75 pF (+127 ppm at the datasheet 7 pF);
    the rev A PA network loses 10-11 dB into 50 ohm, bypassed the PA gives
    0.0 dBm at 0 dBm and +7.5 dBm at +8 dBm
    - N54 current: floor 4.16 uA, System OFF 2.05 uA (about 1.4 uA above the
    datasheet, open), 7.6 uC per advert at 0 dBm against 12.6 uC on C23
    - N54 board status, rework log and corrected RF network description
    - C23: CW board without the PA pi network for the harmonics comparison
    - Root README: board status and the MCU comparison so far
2026-10-28 Record BSN-C23 and BSN-N54 harmonics from the spectrum analyser Conducted harmonics (H1-H5) on the R&S FPH at the uni, each on a 3 MHz span:
    - N54 board #2, PA network bypassed, 0 dBm: H3 -24.3 dBm, 17 dB over the
    FCC restricted-band limit, so rev B needs a harmonic filter
    - C23 without the pi network: H3 fails at 0 dBm (by 0.6 dB), H2 and H3 fail
    at +8 dBm (by 8 and 13 dB)
    - C23 with the pi network: passes at +8 dBm at 2440 and 2480 MHz with at
    least 9.5 dB of margin; H5 is only filtered by about 5 dB
    - Wide sweep 10 MHz-15 GHz: no spurs besides the harmonics; the 2414 MHz
    peak seen on the VNA was its own image response
2026-10-28 Add N54 pwrtest bareoff mode for the System OFF current
    MODE=bareoff resets every GPIO to its power-on default before System OFF.
    Pin settings survive System OFF, so its difference to MODE=shutdown is what
    the firmware's pin configuration costs, for the open 1.4 uA excess.
2026-10-30 Stop the C23 sensor task waking every second after a reload
    The task woke once a second for the whole sensor period to check the payload
    reload, about 2.4 uC per wake-up (14 % of the 16.1 uA full-firmware current).
    It now retries once a second only until the reload has gone through, then
    sleeps out the rest of the period. Not verified yet: the only run with it
    (no-pi board, 5 s advertising) read 6.55 uA against a 3.85 uA model.
2026-10-30 Use GPIO SENSE for the N54 HDC2010 interrupt
    Edges on HDC_INT (P0.01) now go through the low-power SENSE mechanism
    (sense-edge-mask) instead of a GPIOTE IN channel, which can raise the
    System ON idle current. Used by pwrtest sensor_irq.
2026-10-30 Record BSN-N54 sensor, voltage and full-firmware current measurements
    Keysight 34465A, 2026-10-30, the reference set for the battery-life model:
    - N54 floor 4.20 / 4.93 / 5.67 uA at 3.0 / 2.4 / 2.0 V (about constant power);
    System OFF with every GPIO reset about 1.9 uA, so the 1.4 uA excess is not
    the pin setup and is the same on both boards
    - N54 advert 7.58 uC at 3.0 V, +40 % at 2.0 V (C23 +34 %); J1 left open
    costs 5-7 % more
    - N54 sensor reading 2.01 uC with timer polling and 1.78 uC with the DRDY
    wake (C23: 9.56 and 3.72 uC)
    - N54 full firmware at 5 s advertising: 6.1 uA against a 6.01 uA model
    - C23 no-pi board into 50 ohm: 12.30 / 17.30 uC per advert at 3.0 / 2.0 V,
    matching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
2026-10-31 Record the rev B MCU choice: CC2340R5 (BSN-C23)
    hardware/MCU_DECISION.md gives the reasons from the rev A comparison (T0):
    the C23 sleep floor wins at 5 s advertising and slower, even against the
    N54's best case, and the C23 passes the harmonic limits with its pi network
    while the N54 fails H3 by 17 dB. The N54 variant stops at rev A. README
    status updated.
2026-10-31 Rule out the C23 floor as the cause of the 6.55 uA result
    Home check on a UT139S (2026-10-31, indicative): floors of about 0.75 uA
    (board #1), 1.1 uA (no sensors) and 0.5-0.6 uA (no-pi board), nowhere near
    the ~3 uA needed. Next suspect: an extra advert on each payload reload.
    Also adds the ordered N54 floor offset investigation (chip ID / erratum 31,
    supply sweep, capacitors, U1 removal, bake).
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2026-10-31 Stop tracking the interactive HTML BOMs
    The KiCad files are enough to regenerate them, and BOM layout is a
    personal preference.
2026-10-31 Drop the unused results/ folder from the README and add the C23 interval model
    Test results stay next to the board they were measured on. Add the average
    current against advertising interval table to the C23 power measurements,
    and update the README now that the MCU is chosen. Fix the BOM file name.
2026-10-31 Rework the README for visitors and stop hosting vendor datasheets
    Lead the README with a photo of the rev A boards, the highlights, renders and
    schematic/PCB PDFs, and the status, open questions and next steps. Shorten the
    naming scheme and move it to the end.
    Replace the vendor PDFs with a list of the documents and links to them; the
    files stay local and ignored. Mark the N54 folders as concluded at rev A, and
    remove a stray .gitignore line.
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2026-11-02 Correct the rev A antenna match notes: the first match was detuned by the table, not the battery
    The 2026-10-23 match was tuned with the board flat on a wooden table. Lifted about 5 mm by the
    battery holder, the board reads the same as hanging in the air, so the 4.3 nH + 2.1 pF match is
    for the lifted board and the coin cell barely matters.
2026-11-02 C23 rev B: printed IFA, MM8130 test connector and reworked RF layout
    - Chip antenna AE1 replaced by the printed inverted-F antenna from openEMS run r011 (IFA_2G4
    footprint and its generator script). Antenna length still to be re-optimised on the real outline.
    - Murata MM8130-2600 switch connector J2 between the PA network and the antenna, with the In1 and
    In2 cutout from its datasheet.
    - 50 ohm GCPW over solid In1 GND for the whole RF path, via fence, solid GND connection on the
    shunt pads, In2 GND under the RF path and along the antenna ground edge.
    - Pin changes: BOOT on DIO3 (pin 14), LED on DIO4 (pin 15, DNP), HDC2010 INT on DIO13 (pin 6),
    TX on DIO6. DNP 100 uF bulk cap and Digi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
2026-11-03 C23 rev B antenna sims: scripted openEMS pipeline, own far-field transform and design records
    Board export to openEMS, case runner with result cache, server job queue, tuners, matching estimates,
    geometry drawings and per-design records (results/DESIGNS.md). The openEMS NF2FF transform is wrong for the
    layered board, efficiency and pattern now come from farfield.py, validated on a dipole and test benches.
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2026-11-03 Antenna sims: final candidate tolerance runs, queue backfill and thread accounting, LF for shell scripts
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2026-11-04 IFA_2G4 footprint replaced with the final rev B antenna, L4 notes after re-annotation, chosen L2/L3 parts
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2026-11-04 Antenna sims: reports no longer list L4 as an RF part (ref L4 is the DC-DC inductor in rev B)
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2026-11-04 C23 rev B antenna write-up: full report on the b3 board as ordered
    README with summary, dimensions, model assumptions, S11 / Smith / VSWR, tolerance, efficiency budget,
    pattern, fields, movies and ParaView how-to. Figures and data redrawn from the b3 runs d349ba0674
    (1-port), 819dfacd2e (3-port) and 8b668025c7 (lumped L2/L3, 150 mm air). Sim records for the
    3-port and air runs.
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2026-11-04 BOM CSVs no longer tracked, kept locally for ordering, the schematics hold the parts
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
